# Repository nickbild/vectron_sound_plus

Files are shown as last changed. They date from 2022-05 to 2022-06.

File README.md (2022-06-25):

# Vectron Sound Plus

Vectron Sound Plus uses the General Instrument AY-3-8910 sound generator to produce 8-bit retro audio.

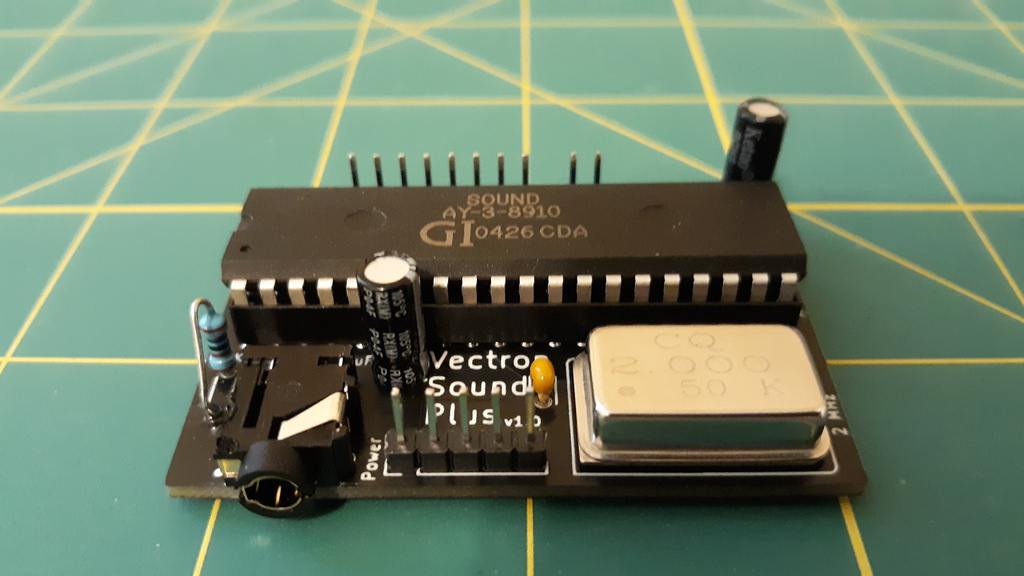
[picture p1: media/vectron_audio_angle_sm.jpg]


## How It Works

The simple design exposes the AY-3-8910's data bus and control pins so that an external system can control it.  The required crystal oscillator and audio output circuitry are also included so that any speaker can be connected via a TRS cable through the onboard jack.

This is the circuit design:


## Media

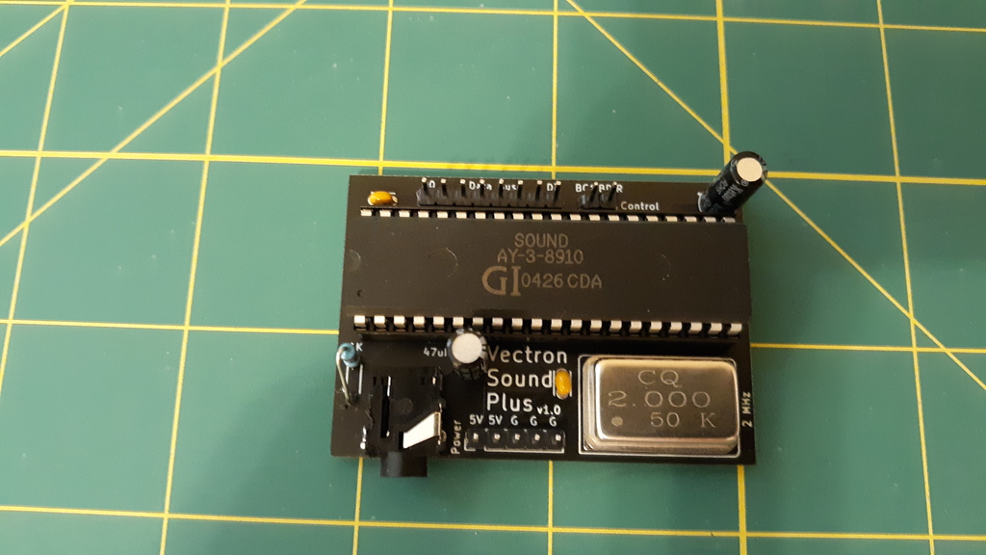
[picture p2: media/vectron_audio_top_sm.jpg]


Here, the Vectron Sound Plus is being controlled by the [Vectron 65 Plus computer](https://github.com/nickbild/vectron_65_plus):

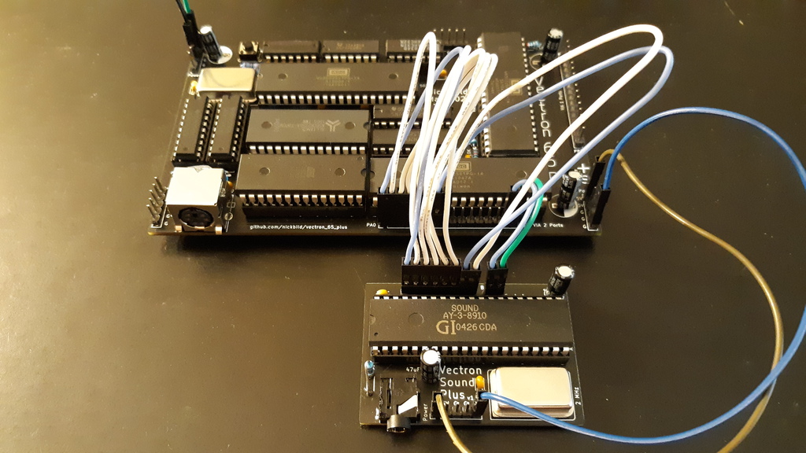
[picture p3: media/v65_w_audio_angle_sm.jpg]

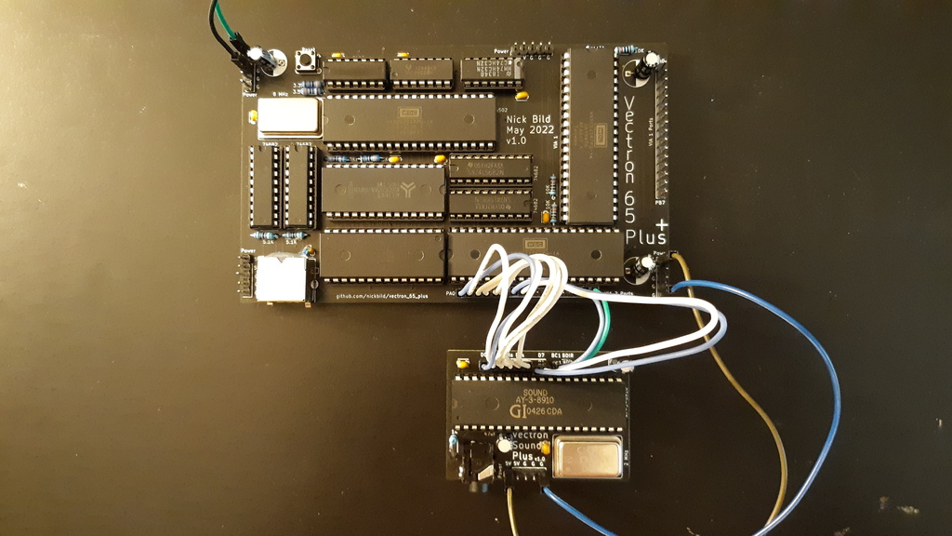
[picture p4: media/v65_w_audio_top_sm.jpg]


You can download an [MP3 here](https://github.com/nickbild/vectron_sound_plus/blob/main/media/vectron_65_audio.mp3?raw=true) of a tune I made with it.

Vectron Sound Plus can also be controlled via a Raspberry Pi using [my Python library](https://github.com/nickbild/ay-3-8910).

## Bill of Materials

- 1 x General Instrument AY-3-8910 sound generator
- 1 x 2 MHz crystal oscillator
- 1 x 220 uF electrolytic capacitor
- 1 x 47 uF electrolytic capacitor
- 1 x 1K resistor
- 2 x 0.1 uF ceramic capacitors
- 1 x TRS jack connector
- 1 x PCB ([Kicad design files](https://github.com/nickbild/vectron_sound_plus/tree/main/vectron_sound_kicad))

## About the Author

[Nick A. Bild, MS](https://nickbild79.firebaseapp.com/#!/)

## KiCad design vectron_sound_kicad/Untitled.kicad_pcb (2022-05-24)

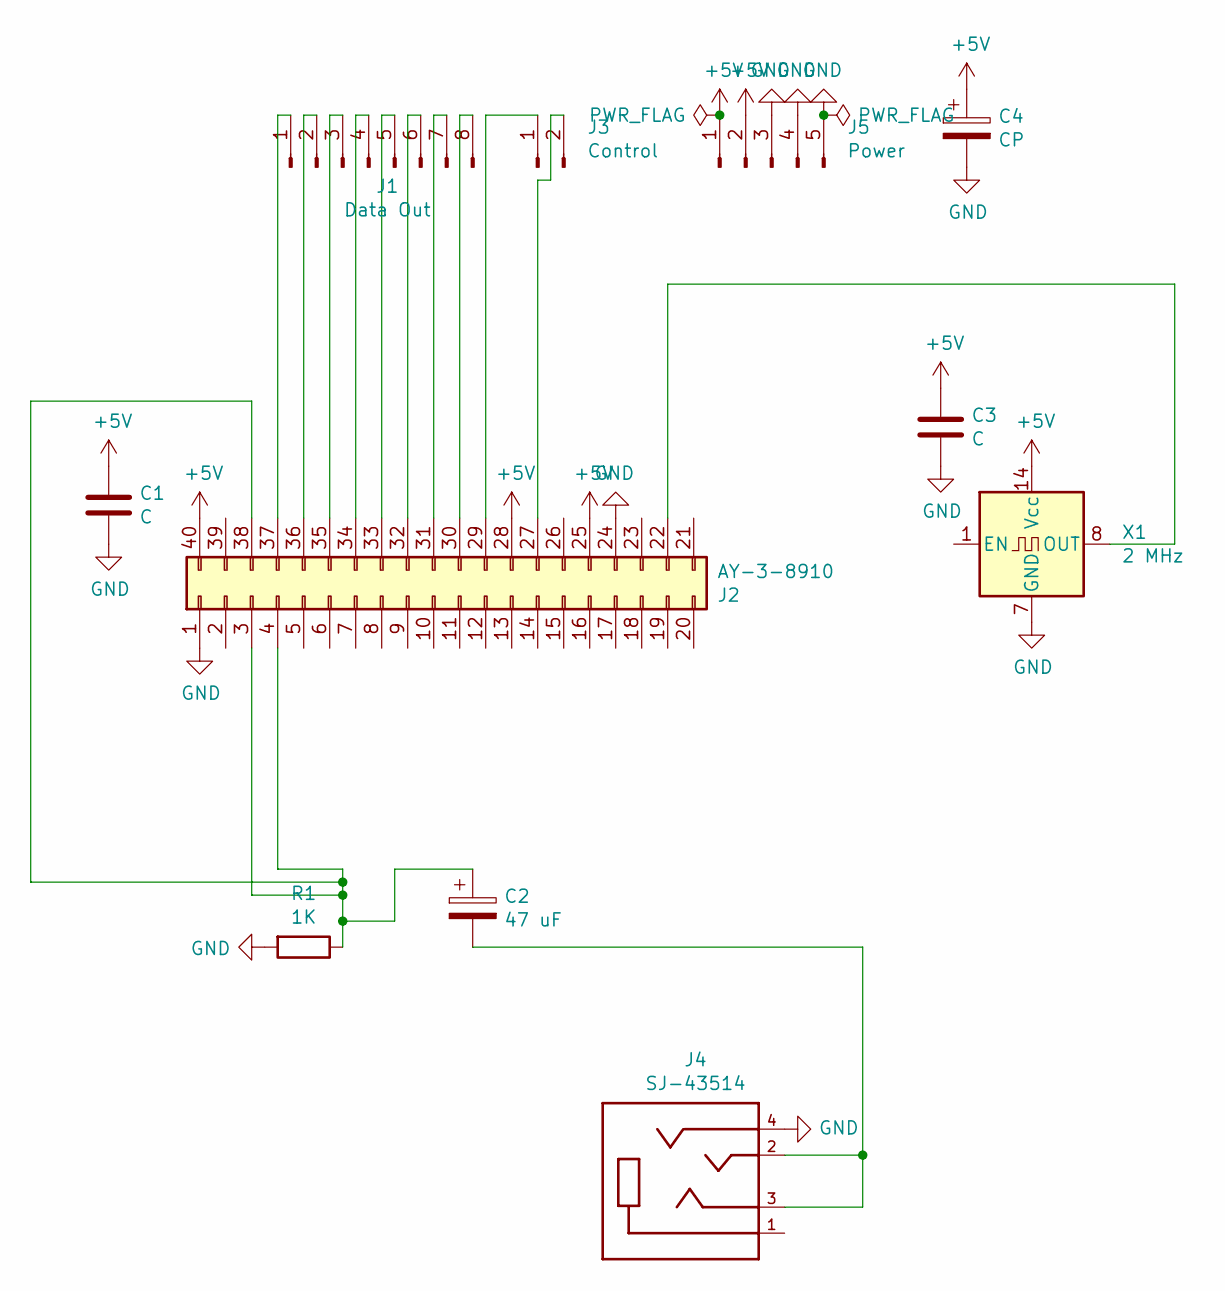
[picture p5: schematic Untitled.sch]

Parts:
C1, C3: C; C_Disc_D3.0mm_W2.0mm_P2.50mm
C2: 47 uF; CP_Radial_D4.0mm_P2.00mm
C4: CP; CP_Radial_D5.0mm_P2.50mm
J1: Data Out; PinHeader_1x08_P2.54mm_Vertical
J2: AY-3-8910; DIP-40_W15.24mm
J3: Control; PinHeader_1x02_P2.54mm_Vertical
J4: SJ-43514; CUI_SJ-43514; PART_REV 1.04
J5: Power; PinHeader_1x05_P2.54mm_Vertical
R1: 1K; R_Axial_DIN0204_L3.6mm_D1.6mm_P5.08mm_Horizontal
X1: 2 MHz; Oscillator_DIP-14

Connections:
+5V: C1.1, C3.1, C4.1, J2.25, J2.28, J2.40, J5.1, J5.2, X1.14 (Vcc)
GND: C1.2, C3.2, C4.2, J2.1, J2.24, J4.4, J5.3, J5.4, J5.5, R1.2, X1.7 (GND)
unnamed: C2.1, J2.3, J2.4, J2.38, R1.1
unnamed: C2.2, J4.2, J4.3
unnamed: J1.1, J2.37
unnamed: J1.2, J2.36
unnamed: J1.3, J2.35
unnamed: J1.4, J2.34
unnamed: J1.5, J2.33
unnamed: J1.6, J2.32
unnamed: J1.7, J2.31
unnamed: J1.8, J2.30
unnamed: J2.22, X1.8 (OUT)
unnamed: J2.27, J3.2
unnamed: J2.29, J3.1

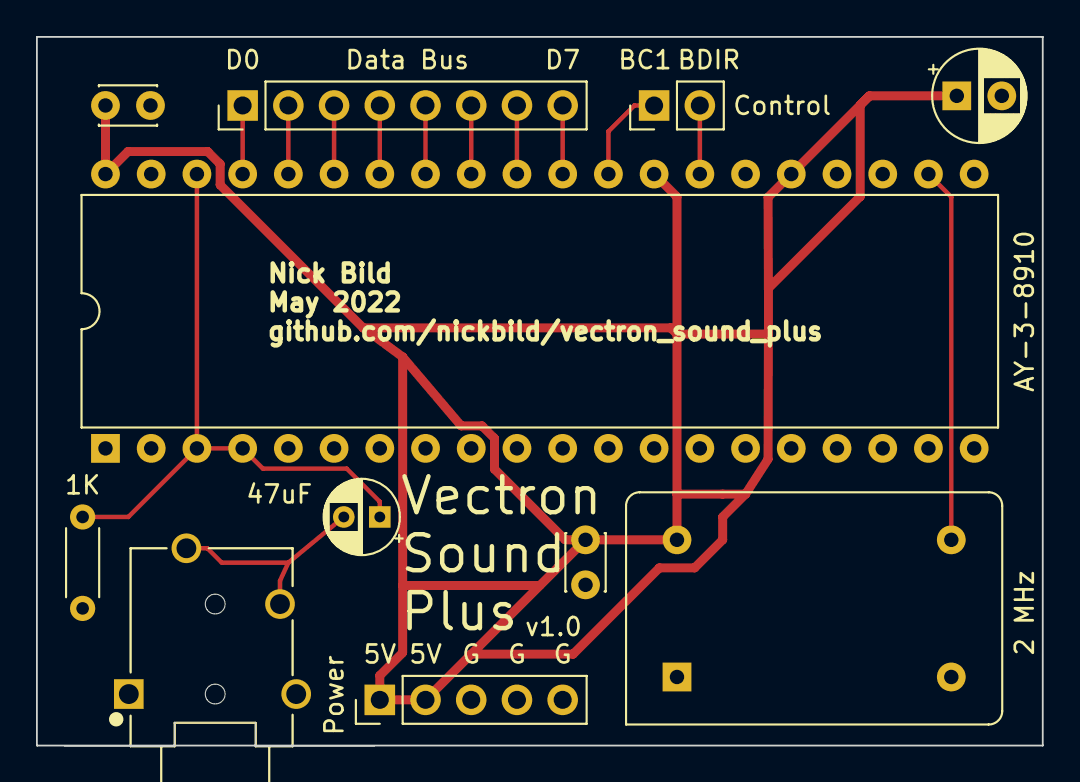
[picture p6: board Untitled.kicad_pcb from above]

Board: 2 copper layers, 55.9 x 39.4 mm, 11 parts (0 on the bottom side), 15 nets.

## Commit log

2022-05-24 Add KiCad design files.
    [Untitled.kicad_pcb, Untitled.sch]
2022-06-25 Add audio sample.
